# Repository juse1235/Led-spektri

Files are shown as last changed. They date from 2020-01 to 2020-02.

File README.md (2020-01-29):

# Led-spektri
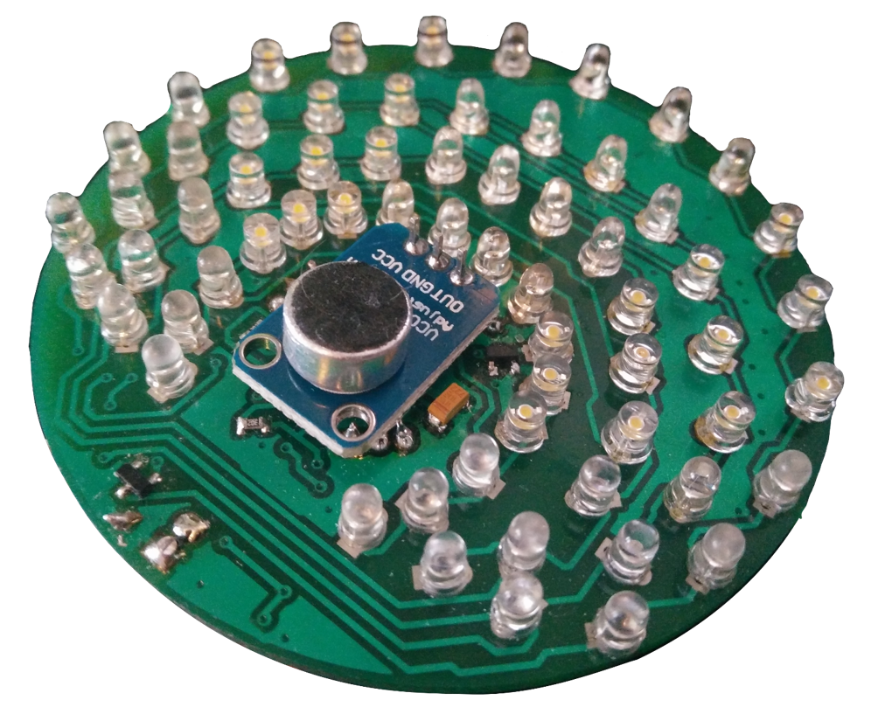
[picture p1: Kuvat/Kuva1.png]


Tuntuiko normaali haalarisalama liian yksinkertaiselta? Epäiletkö, että juotettavia LEDejä ei voi olla liikaa? Oletko aina haaveillut haalarimerkistä, jonka nähtyään kanssaopiskelijat pyörtyvät ihastuksesta?

Mikäli näin on, olet selvästikin motivoitunut nousemaan seuraavalle tasolle yöllisessä yökerhojen ja pystärien bling-bling-loisteessa. Tämä tanssilattioiden katseenvangitsija tarjoaa ainutkertaisen mahdollisuuden turruttaa itsensä vinoon juottuneille komponenteille ja v*tutukselle. Älä missaa tilaisuutta! Minä en missaisi.

Komponentit

| Tyyppi |	Määrä  |	Huom |
| --- | --- | --- |
| Atmega328PB-AU  |1 |	Myös 328P voi toimia, mutta vaatii muutoksia kääntäjään |
| LED, 3 mm, jalallinen	|64 |	Ei värikoodia – käytä mielikuvitusta |
| Transistori, SOT-23|16 |	Käytössä MMBT4401, ei suurempaa väliä mallista, hyvä kuitenkin kestää vähintään 20 mA virtaa |
| Vastus, 0603 – 0805, 1+ kOhm | 16 |		Transistorien ohjaus |
| Etuvastus, 0805	|8	| Kirkkauden säätö, 100 – 500 ohmia lienee hyvä, säätää myös virrankulutusta, tekijällä käytössä 300 ohmia |
| Isohko vastus, noin 5 kOhm, 0603 |2	 | |
| Regulaattori, LP2985 – 3.3 |	1	| |
| Kondensaattori, 100 nF, 0805|	1	| |
| Kondensaattori, 10 uF, 0805|	1	| |
| Sulake, 500 mA, 1206	|1	| |
| Oskillaattori, 16 MHz |	1 |	Käytössä CSTCE16M0V53-R0 |
| MAX4466-mikrofonimoduuli |	1 |	Mikrofoneja löytyy eri herkkyyksillä, voi olla tuurissaan, mikä on käyttökelpoinen. Electret sinisellä piirilevyllä on toiminut toistaiseksi.|

## Yleinen toimintaperiaate
Ledien toimintaperiaate on samankaltainen kuin haalarisalamassakin, eli ledejä vilkutetaan matriisissa sarakkeittain säätämällä, mikä sarake saa yhteyden maahan ja suljettua virtapiirin. 

Mikrofoni kuuntelee ääntä, ja mikrokontrolleri lukee siitä tulevaa analogista signaalia jatkuvalla syötöllä. Näytepätkän ollessa valmis mikrokontrolleri tekee siitä fft-muunnoksen, joka voidaan esittää ledeillä.

Tähän merkkiin ei otettu edes mahdollisuudeksi käyttää 9 voltin paristolla, vaan käyttöjännite otetaan aina 5 voltin jännitelähteestä (lue: USB-kaapelin kautta varavirtalähteestä).

## Tarkempi piirikaavion analyysi
Piirikaavion olisi voinut päivittää paljon helpommin luettavaksi ja oikeille arvoille, jos Kicad 5.0 ei olisi niin epäyhteensopiva Kicad 4 -versioiden kanssa. 

Käyttöjännite tulee mikrokontrollerille ja 3,3 voltin regulaattorille sulakkeen kautta. Sulakkeen tehtävänä on luonnollisesti edes hieman suojata komponentteja oikosuluilta sun muilta lapsuksilta. Tässä otettiin mallia Arduinosta. Regulaattorin tarkoituksena on vain ja ainoastaan tuottaa tasaista käyttöjännitettä mikrofonimoduulille ja asettaa analoginen referenssitaso mikrokontrollerille mikrofonimoduulin analogisen signaalin lukua varten. 10 mikrofaradin kondensaattori C1 tasoittaa käyttöjännitteen pahimmat häiriöt, ja kondensaattori C_small (oikea arvo 100 nF) tekee saman 3,3 voltin linjalle.

Toisin kuin haalarisalamassa, tässä projektissa tarvitaan transistoreita rajoittamaan mikrokontrollerin kuormaa. Riittävän kirkkauden takaamiseksi ledin virraksi on hyvä määritellä noin 15 mA. Transistoreiksi päätyivät MMBT3904-transistorit, jotka perustuvat NPN-teknologiaan. Lähtökohtaisesti MOSFET-transistorienkin pitäisi toimia ihan yhtä hyvin, kunhan paketointi on sama. Transistorit vaativat vastukset kantavirran rajoittamiseksi (1 kOhmin vastukset piirikaaviossa ja jäljempänä esitetyssä piirilevyssä). Todennäköisesti arvoltaan suuremmatkin vastukset toimisivat aivan yhtä hyvin. 

##### HUOM!Projektia kokeiltiin toteuttaa myös puolella transistorimäärällä, mutta mikrokontrolleri ei kyennyt antamaan riittävästi virtaa yhden sarakkeen ledeille yhtä aikaa. Tämän korjaaminen vaatii joko todella herkkiä ja kirkkaita ledejä ja/tai koodimuutoksia, jolloin ainoastaan yksi led olisi samaan yhtä aikaa päällä (nyt maksimissaan kahdeksan).

Oskillaattori on geneerinen 16 megahertsin malli sisäänrakennetulla kuormakapasitanssilla, jollaisia näkee muun muassa Arduino Nanossa. Myös 20 megahertsin kidettä voi käyttää, mutta se vaatii muutoksia koodiin ja Atmegan… ööö, fuse… sulake ei liene oikea termi. Joka tapauksessa ”fuse”:ille pitää löytää oikeat asetukset.

Yksinkertaisuuden vuoksi mikrofonin kanssa päädyttiin vahvistimen sisältävään valmiiseen moduuliin. Moduuli tuottaa analogista signaalia, joka välitetään Atmegan ADC-pinniin, ja josta Atmega ottaa näytepätkän.

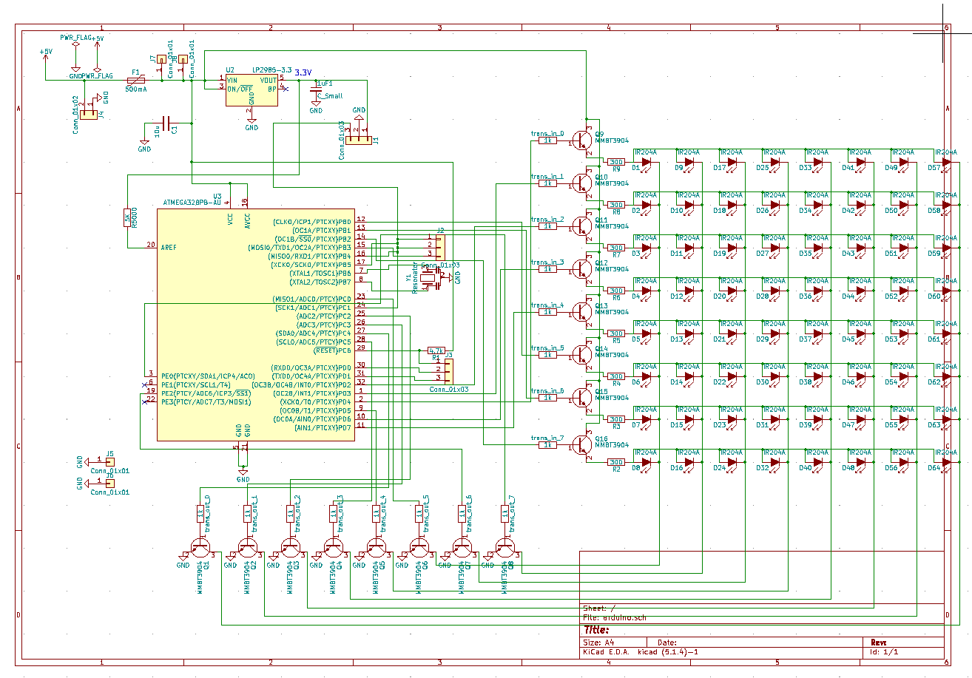
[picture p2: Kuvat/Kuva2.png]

Kuten tarkimmat jo saattavat huomata, tekijä ei osannut tekovaiheessa tehdä ihmisystävällisiä kytkentöjä.

## Piirilevy
Tilanpuute oli valtava ongelma varsinaisen piirilevyn suunnittelun kanssa. Tästä syystä kaikkia komponentteja ei voitu sijoittaa levyn takapuolelle helpon korjattavuuden takaamiseksi, vaan osa komponenteista ja mikrofonimoduuli oli juotettava etupuolelle.

Yleinen ohje juottamiseen: juota ensin yksi komponentin nurkka kiinni niin, että komponentin muutkin juotoskohdat ovat paikallaan ja komponentti on oikeassa asennossa. Tämän jälkeen voi helposti juottaa loput paikat.

Juottaminen on hyvä aloittaa mikrokontrollerista. Tekijä juotti piirin reippaalla juoksutteella ja reippaalla tinankäytöllä, jolloin myös kontrollerin jalat olivat juottuneet yhteen. Tämän jälkeen ylimääräinen tina oli helppoa imeä tinaimunauhalla.

Muiden pintaliitoskomponenttien juottamisessa ei ole varsinaisesti mitään mainittavaa. U2 alemmassa kuvassa on 3,3 voltin regulaattori.
Kun pintaliitoskomponentit on juotettu, J7 ja J6 on yhdistettävä hyppylangalla. Miksi näin? Tilanpuutteen takia maatasoa ei ole muuten yhdistetty kontrollerin yläpuolelle ollenkaan. Onneksi tämä on matalan taajuuden sovellutus, joten tämmöiset temput ovat sallittuja...

Etupuolella on mainittava ledien juottamisesta sen verran, että pitkä jalka (anodi) menee ympyrän muotoiseen juotospisteeseen, ja lyhyt jalka (katodi) menee neliön muotoiseen juotospisteeseen. Kokemuksen jykevällä rintaäänellä voi sanoa, että juottakaa ledit myös mieluummin etupuolelle kuin takapuolelle. Mikrofonimoduulin ja piirilevyn väliin on suositeltavaa laittaa jotakin eristettä oikosulun välttämiseksi. Tantaalikondensaattorin viivalla merkitty pääty menee aina positiiviseen jännitteeseen kaiken järjen vastaisesti (etupuolen 10 mikrofaradin konkka). 

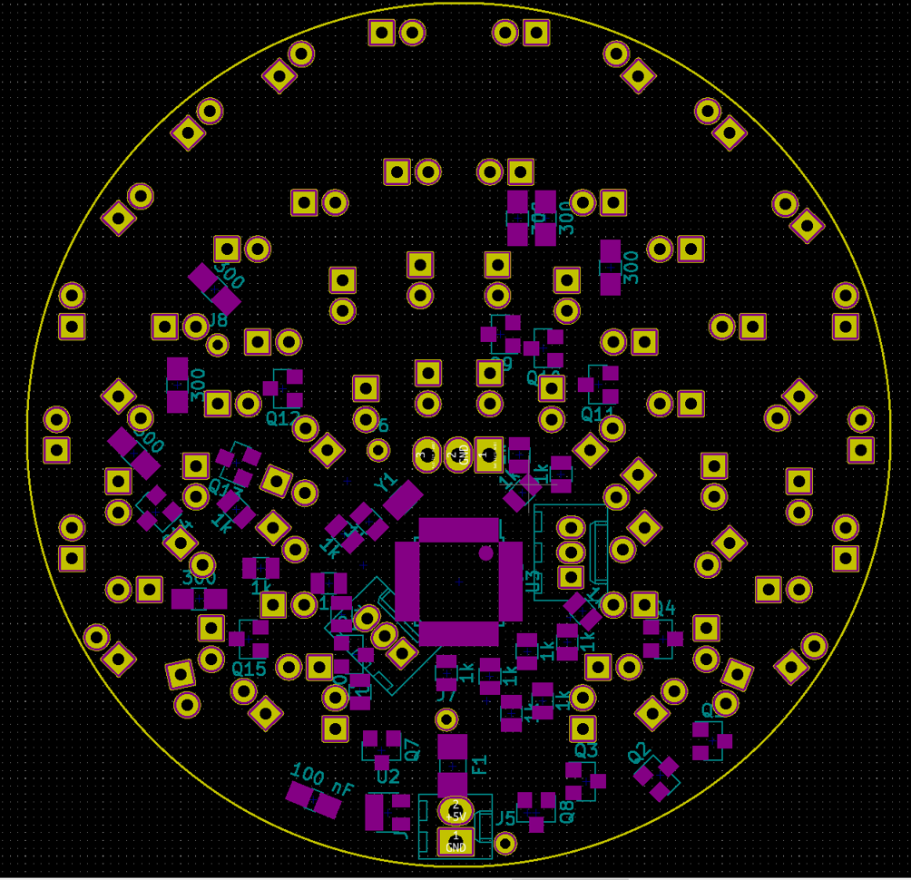
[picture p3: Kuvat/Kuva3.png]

Levyn takapuoli

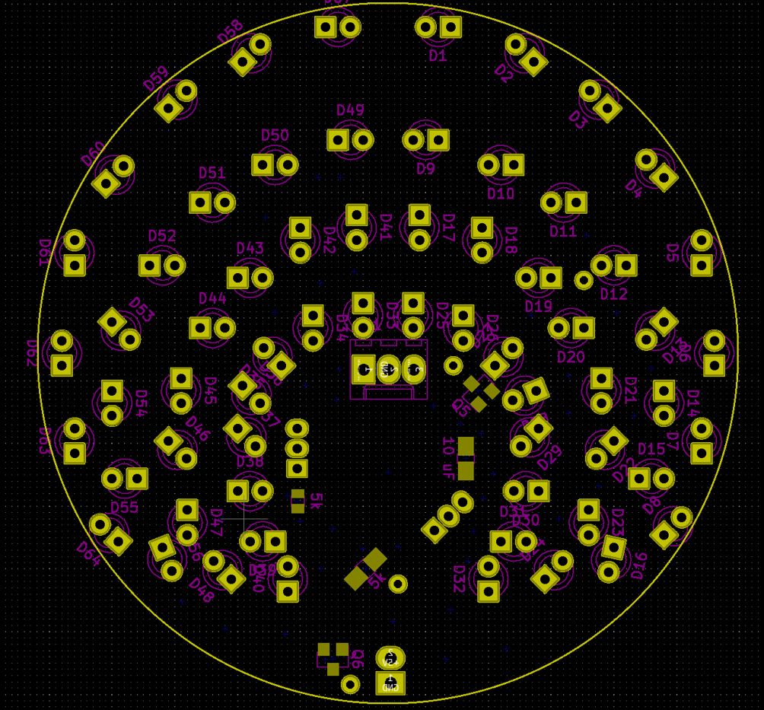
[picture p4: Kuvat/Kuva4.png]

Levyn etupuoli

## Ohjelmointi
Ohjelmointi tapahtuu ISP-väylän kautta. ArduinoISP on tässä suositeltava ohjelmoija. Piirilevylle jätettiin ohjelmointipaikat myös UART-ohjelmointia varten, mutta niitä ei tässä tapauksessa tarvita ollenkaan. Tulevaisuuden generaatioista ne voikin poistaa tilaa säästääkseen.

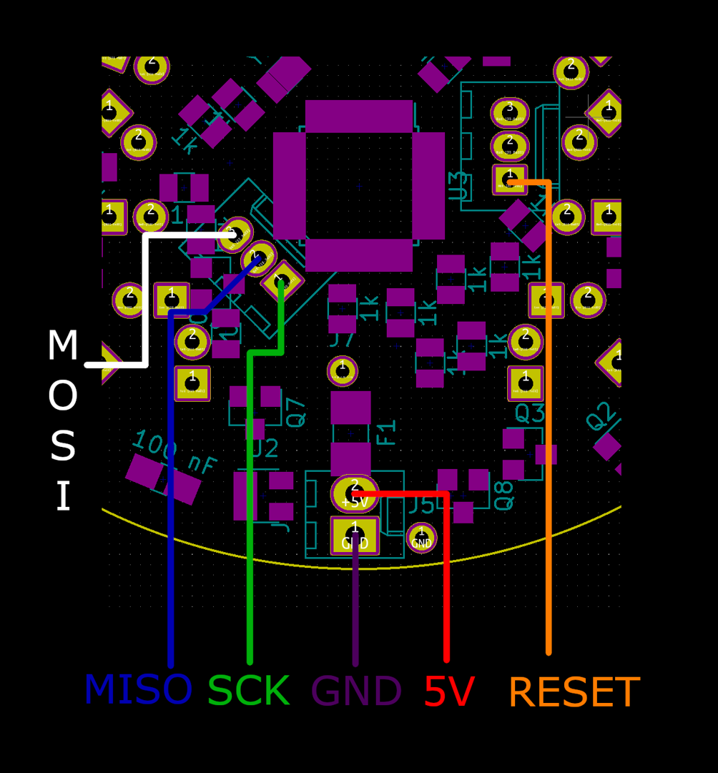
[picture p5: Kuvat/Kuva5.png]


##### Komennot Windowsille:

avrdude -C "C:\Program Files (x86)\Arduino\hardware\tools\avr\etc\avrdude.conf" -c avrisp -p m328pb -B3 -P COM7 -b 19200 -U flash:w:merkki.hex

avrdude -C "C:\Program Files (x86)\Arduino\hardware\tools\avr\etc\avrdude.conf" -c avrisp -p m328pb -B3 -P COM7 -b 19200 -U lfuse:w:0xff:m -U hfuse:w:0xde:m efuse:w:0x05:m

Jos avrdude.exe:ä ei ole asetettu Windowsin ympäristömuuttujiin, on edellä mainitut komennot ajettava ”Arduino\hardware\tools\avr\bin”-kansiosta. Polut ja oikea sarjaportti pitää toki tarkistaa tapauskohtaisesti.

##### Testaamattomat komennot Linuxille ja Macille:

avrdude -c avrisp -p m328pb -B3 -P /dev/ttyUSB0 -b 19200 -U flash:w:merkki.hex

avrdude -c avrisp -p m328pb -B3 -P /dev/ttyUSB0 -b 19200 -U lfuse:w:0xff:m -U hfuse:w:0xde:m efuse:w:0x05:m

Atmel Studio 7:llä tehty koodi ei ole mitään kauneinta katseltavaa, mutta joka tapauksessa se toimii. ChaN AVR FFT -kirjasto on otettu lievästi editoituna AVRFreaks-foorumilta ( https://www.avrfreaks.net/forum/64-point-fft-elm-chan-library), ja kirjasto löytyy myös erilaisina variaatioina eri puolilta internetiä. Alun perin koodi on oletettavasti julkaistu Elm-chanin kotisivulla (http://elm-chan.org/works/akilcd/report_e.html)

## Fyysinen rakenne
Kuumaliimaa kannattaa hyödyntää ainakin varsinaisen mikrofonielementin ja mikrofonimoduulipiirilevyn liitoskohdassa, sillä isku taittaa mikrofonin helposti. Lisäksi käyttöjännitetuloon on hyvä tehdä liimalla vedonpoisto.
Haalarimerkkiin integroimiseen ei ole suoria ohjeita, mutta on suositeltavaa tehdä painettuun merkkiin valmiit reiät. Mielikuvituksen ja insinööritaitojen käyttö on aiheellista, sillä ledien asentaminen merkin läpi haalarisalaman mukaisesti ei ole huollettavuuden takia järkevää.

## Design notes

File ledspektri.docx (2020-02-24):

Spektrianalysaattori – LED-mössö haalareihin

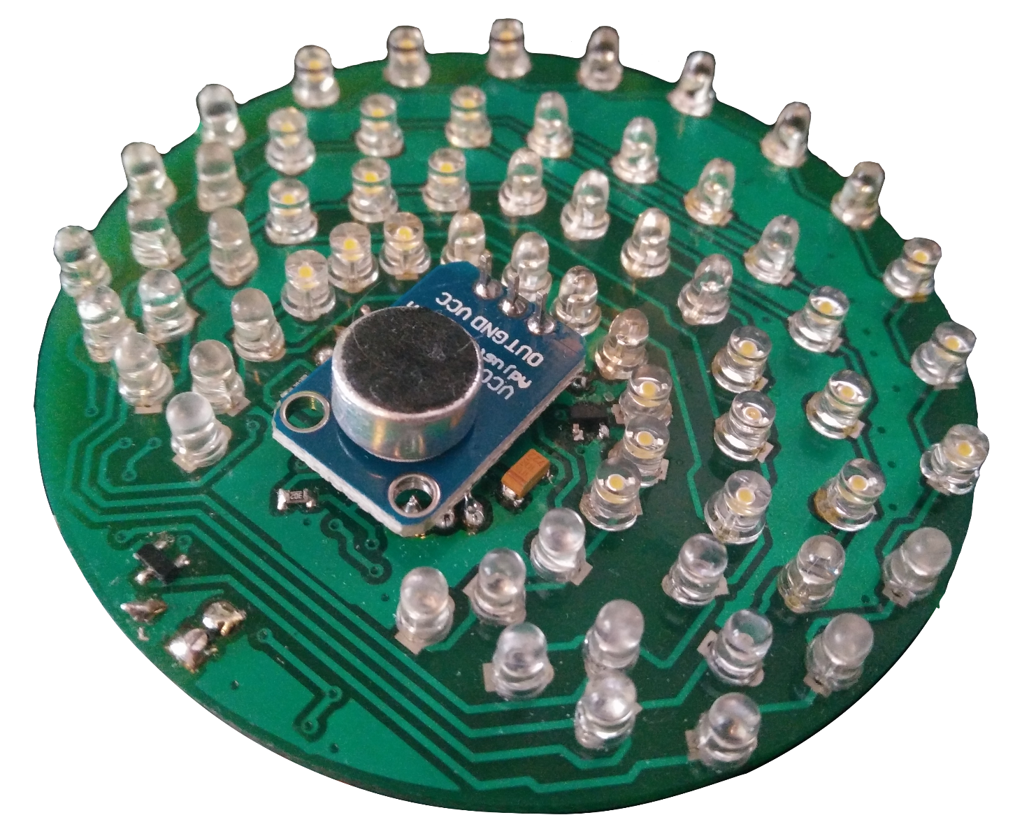
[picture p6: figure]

Tuntuiko normaali haalarisalama liian yksinkertaiselta? Epäiletkö, että juotettavia LEDejä ei voi olla liikaa? Oletko aina haaveillut haalarimerkistä, jonka nähtyään kanssaopiskelijat pyörtyvät ihastuksesta?

Mikäli näin on, olet selvästikin motivoitunut nousemaan seuraavalle tasolle yöllisessä yökerhojen ja pystärien bling-bling-loisteessa. Tämä tanssilattioiden katseenvangitsija tarjoaa ainutkertaisen mahdollisuuden turruttaa itsensä vinoon juottuneille komponenteille ja v*tutukselle. Älä missaa tilaisuutta! Minä en missaisi.

Historiikki

Jo fuksivuonna pienen teekkarinalun mielessä muhi ajatus pidemmälle viedystä haalarimerkistä, joka tekisi jotakin erilaista. Jotakin, joka aiheuttaisi edes pientä kysymysmerkkiä kanssaeläjissä Oulun yössä. Syntyi idea omasta haalareihin kiinnitettävästä spektrianalysaattorista, johon löytyi Arduino-pohjalle tehtyjä valmiita ohjeita netistä pilvin pimein. Kummasti yhtäkään ei ollut suunniteltu haalareihin sopivaksi.

Sopivan markkinaraon löydyttyä oli aika pyörähtää Fablabilla jyrryyttämässä Arduinoon shieldinä sopiva piirilevy. Latomisen jälkeen pikainen softaus ja kappas – nythän käsissä oli toimiva kapistus. Vielä polkupyörän sisäkumista tehty IP67-suojaus, niin sehän oli täydellinen!

Ylpeää fuksiahan eivät haitanneet kyhäelmän paino, joka oli luokkaa Jupiter, tai ulkonäkö, jonka rinnalla renkaan alle jäänyt oravakin näytti hyvän mielen taideteokselta. Toisen lahkeen valuminen painon alla kohti nilkkaa toki pientä kysymysmerkkiä kaupungilla aiheuttikin, mutta kohteliaana kansana suurin osa oululaisista osasi pitää turpansa kiinni.

Wappuna muuan kanssaopiskelija uskalsi viimein avata suunsa ja heitti ilmoille kysymyksen koskien tehokkaampaa ja hiotumpaa merkin rakennetta. Huolimatta tiukasta puolustuspuheesta, miksi tämä rakenne on ehdoton ja paras, kysymys jäi kummittelemaan mieltä.

Loppuvuoden 2017 ja alkuvuoden 2018 aikana syntyi monta konseptia aiheesta. Turhankin monta, sillä suurin ongelma oli joka kerta väärän kokoinen tulojännitteen stabilointikondensaattori. On myös mainitsemisen arvoista, kuinka monta komponenttia pystyy juottamaan väärinpäin alkaen ledeistä ja jatkuen mikrokontrollerin kautta tantaalikondensaattoriin. Jokaisesta tuli mitä mielenkiintoisimpia ominaisefektejä tai -hajuja.

Lopulta pitkällisen yrittämisen jälkeen tähdet osuivat kohdalleen, ja uusi kompakti led-merkki oli syntynyt. Suunnitellusti piirilevy oli neulan halkaisijan verran pienempi kuin normaalikokoinen haalarimerkki, mikä laskettakoon voitoksi.

Merkki luvattiin elektroniikkakerhon käyttöön jo vaalikokouksessa vuoden 2018 lopulla, mutta asioiden tapahtumisen ja tapahtumattomuuden takia näin ei käynyt vielä 2010-luvulla. Nyt uuden vuosikymmenen pamahdettua käyntiin olikin korkea aika tarjota elektroniikkakerholle lisää kivaa räpellettävää nykyisille ja tuleville kerhossa kävijöille.

Make elekerho great again!

Juuso Tapaninen 2020

Komponentit

Tyyppi | Määrä | Huom
Atmega328PB-AU | 1 | Myös 328P voi toimia, mutta vaatii muutoksia kääntäjään
LED, 3 mm, jalallinen | 64 | Ei värikoodia – käytä mielikuvitusta
Transistori, SOT-23 | 16 | Käytössä MMBT3904, ei erityisen tarkkaa mallista
Vastus, 0603 – 0805, 1+ kOhm | 16 | Transistorien ohjaus
Etuvastus, 0805 | 8 | Kirkkauden säätö, 100 – 500 ohmia lienee hyvä, säätää myös virrankulutusta, tekijällä käytössä 300 ohmia
Isohko vastus, noin 5 kOhm, 0603 | 2
Regulaattori, LP2985 – 3.3 | 1
Kondensaattori, 100 nF, 0805 | 1
Kondensaattori, 10 uF, 0805 | 1
Sulake, 500 mA, 1206 | 1
Oskillaattori, 16 MHz | 1 | Käytössä CSTCE16M0V53-R0
MAX4466-mikrofonimoduuli | 1 | Mikrofoneja löytyy eri herkkyyksillä, voi olla tuurissaan, mikä on käyttökelpoinen. Electret sinisellä piirilevyllä on toiminut toistaiseksi.

Yleinen toimintaperiaate

Ledien toimintaperiaate on samankaltainen kuin haalarisalamassakin, eli ledejä vilkutetaan matriisissa sarakkeittain säätämällä, mikä sarake saa yhteyden maahan ja suljettua virtapiirin.

Mikrofoni kuuntelee ääntä, ja mikrokontrolleri lukee siitä tulevaa analogista signaalia jatkuvalla syötöllä. Näytepätkän ollessa valmis mikrokontrolleri tekee siitä fft-muunnoksen, joka voidaan esittää ledeillä.

Tähän merkkiin ei otettu edes mahdollisuudeksi käyttää 9 voltin paristolla, vaan käyttöjännite otetaan aina 5 voltin jännitelähteestä (lue: USB-kaapelin kautta varavirtalähteestä).

Tarkempi piirikaavion analyysi

Piirikaavion olisi voinut päivittää paljon helpommin luettavaksi ja oikeille arvoille, jos Kicad 5.0 ei olisi niin epäyhteensopiva Kicad 4 -versioiden kanssa.

Käyttöjännite tulee mikrokontrollerille ja 3,3 voltin regulaattorille sulakkeen kautta. Sulakkeen tehtävänä on luonnollisesti edes hieman suojata komponentteja oikosuluilta sun muilta lapsuksilta. Tässä otettiin mallia Arduinosta. Regulaattorin tarkoituksena on vain ja ainoastaan tuottaa tasaista käyttöjännitettä mikrofonimoduulille ja asettaa analoginen referenssitaso mikrokontrollerille mikrofonimoduulin analogisen signaalin lukua varten. 10 mikrofaradin kondensaattori C1 tasoittaa käyttöjännitteen pahimmat häiriöt, ja kondensaattori C_small (oikea arvo 100 nF) tekee saman 3,3 voltin linjalle.

Toisin kuin haalarisalamassa, tässä projektissa tarvitaan transistoreita rajoittamaan mikrokontrollerin kuormaa. Riittävän kirkkauden takaamiseksi ledin virraksi on hyvä määritellä noin 15 mA. Transistoreiksi päätyivät MMBT3904-transistorit, jotka perustuvat NPN-teknologiaan. Lähtökohtaisesti MOSFET-transistorienkin pitäisi toimia ihan yhtä hyvin, kunhan paketointi on sama. Transistorit vaativat vastukset kantavirran rajoittamiseksi (1 kOhmin vastukset piirikaaviossa ja jäljempänä esitetyssä piirilevyssä). Todennäköisesti arvoltaan suuremmatkin vastukset toimisivat aivan yhtä hyvin.

HUOM! Projektia kokeiltiin toteuttaa myös puolella transistorimäärällä, mutta mikrokontrolleri ei kyennyt antamaan riittävästi virtaa yhden sarakkeen ledeille yhtä aikaa. Tämän korjaaminen vaatii joko todella herkkiä ja kirkkaita ledejä ja/tai koodimuutoksia, jolloin ainoastaan yksi led olisi samaan yhtä aikaa päällä (nyt maksimissaan kahdeksan).

Oskillaattori on geneerinen 16 megahertsin malli sisäänrakennetulla kuormakapasitanssilla, jollaisia näkee muun muassa Arduino Nanossa. Myös 20 megahertsin kidettä voi käyttää, mutta se vaatii muutoksia koodiin ja Atmegan… ööö, fuse… sulake ei liene oikea termi. Joka tapauksessa ”fuse”:ille pitää löytää oikeat asetukset.

Yksinkertaisuuden vuoksi mikrofonin kanssa päädyttiin vahvistimen sisältävään valmiiseen moduuliin. Moduuli tuottaa analogista signaalia, joka välitetään Atmegan ADC-pinniin, ja josta Atmega ottaa näytepätkän.

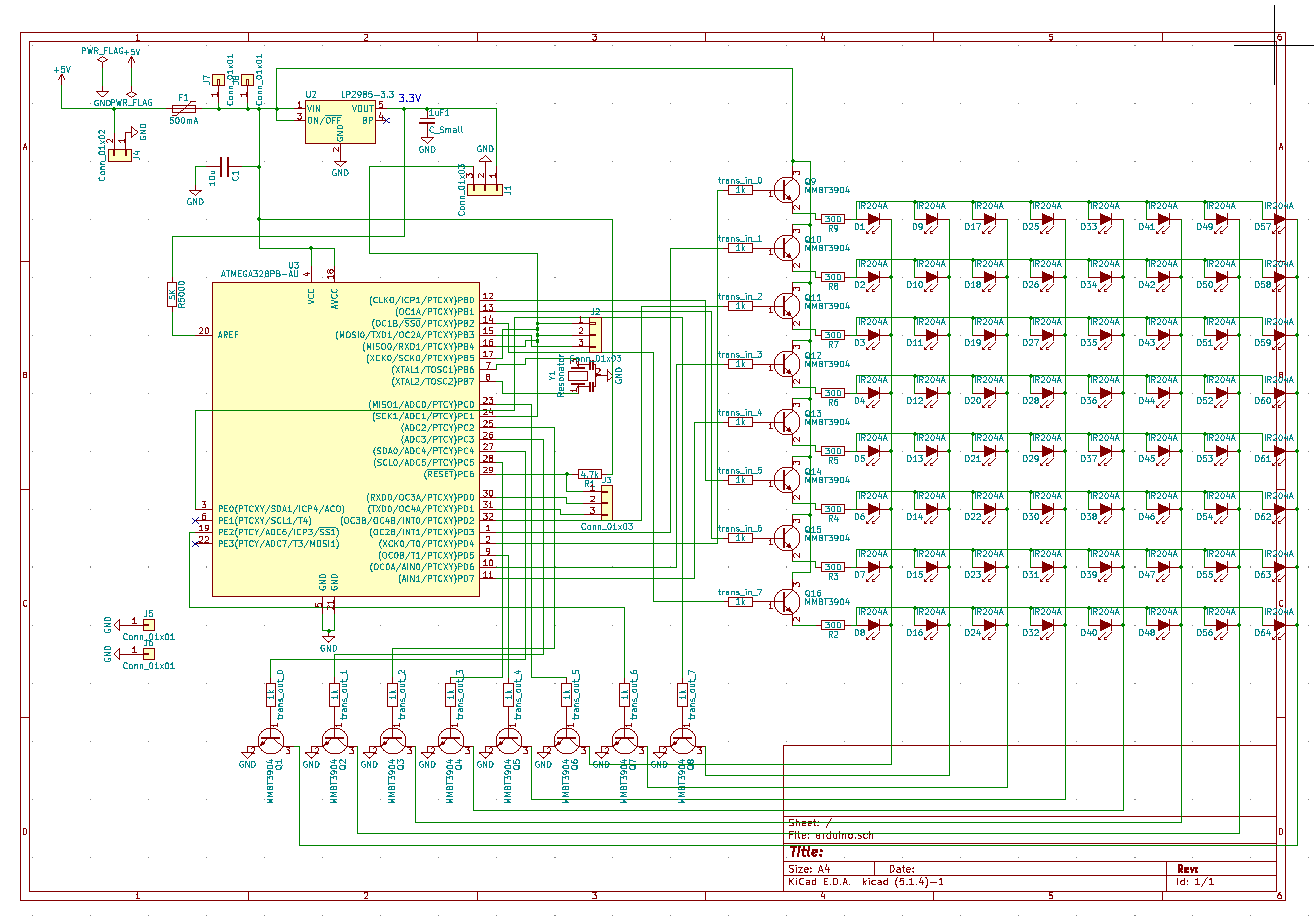
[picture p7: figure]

Kuten tarkimmat jo saattavat huomata, tekijä ei osannut tekovaiheessa tehdä ihmisystävällisiä kytkentöjä.

Piirilevy

Tilanpuute oli valtava ongelma varsinaisen piirilevyn suunnittelun kanssa. Tästä syystä kaikkia komponentteja ei voitu sijoittaa levyn takapuolelle helpon korjattavuuden takaamiseksi, vaan osa komponenteista ja mikrofonimoduuli oli juotettava etupuolelle.

Yleinen ohje juottamiseen: juota ensin yksi komponentin nurkka kiinni niin, että komponentin muutkin juotoskohdat ovat paikallaan ja komponentti on oikeassa asennossa. Tämän jälkeen voi helposti juottaa loput paikat.

Juottaminen on hyvä aloittaa mikrokontrollerista. Tekijä juotti piirin reippaalla juoksutteella ja reippaalla tinankäytöllä, jolloin myös kontrollerin jalat olivat juottuneet yhteen. Tämän jälkeen ylimääräinen tina oli helppoa imeä tinaimunauhalla.

Muiden pintaliitoskomponenttien juottamisessa ei ole varsinaisesti mitään mainittavaa. U2 alemmassa kuvassa on 3,3 voltin regulaattori.

Kun pintaliitoskomponentit on juotettu, J7 ja J6 on yhdistettävä hyppylangalla. Miksi näin? Tilanpuutteen takia maatasoa ei ole muuten yhdistetty kontrollerin yläpuolelle ollenkaan. Onneksi tämä on matalan taajuuden sovellutus, joten tämmöiset temput ovat sallittuja...

Etupuolella on mainittava ledien juottamisesta sen verran, että pitkä jalka (anodi) menee ympyrän muotoiseen juotospisteeseen, ja lyhyt jalka (katodi) menee neliön muotoiseen juotospisteeseen. Kokemuksen jykevällä rintaäänellä voi sanoa, että juottakaa ledit myös mieluummin etupuolelle kuin takapuolelle. Mikrofonimoduulin ja piirilevyn väliin on suositeltavaa laittaa jotakin eristettä oikosulun välttämiseksi. Tantaalikondensaattorin viivalla merkitty pääty menee aina positiiviseen jännitteeseen kaiken järjen vastaisesti (etupuolen 10 mikrofaradin konkka).

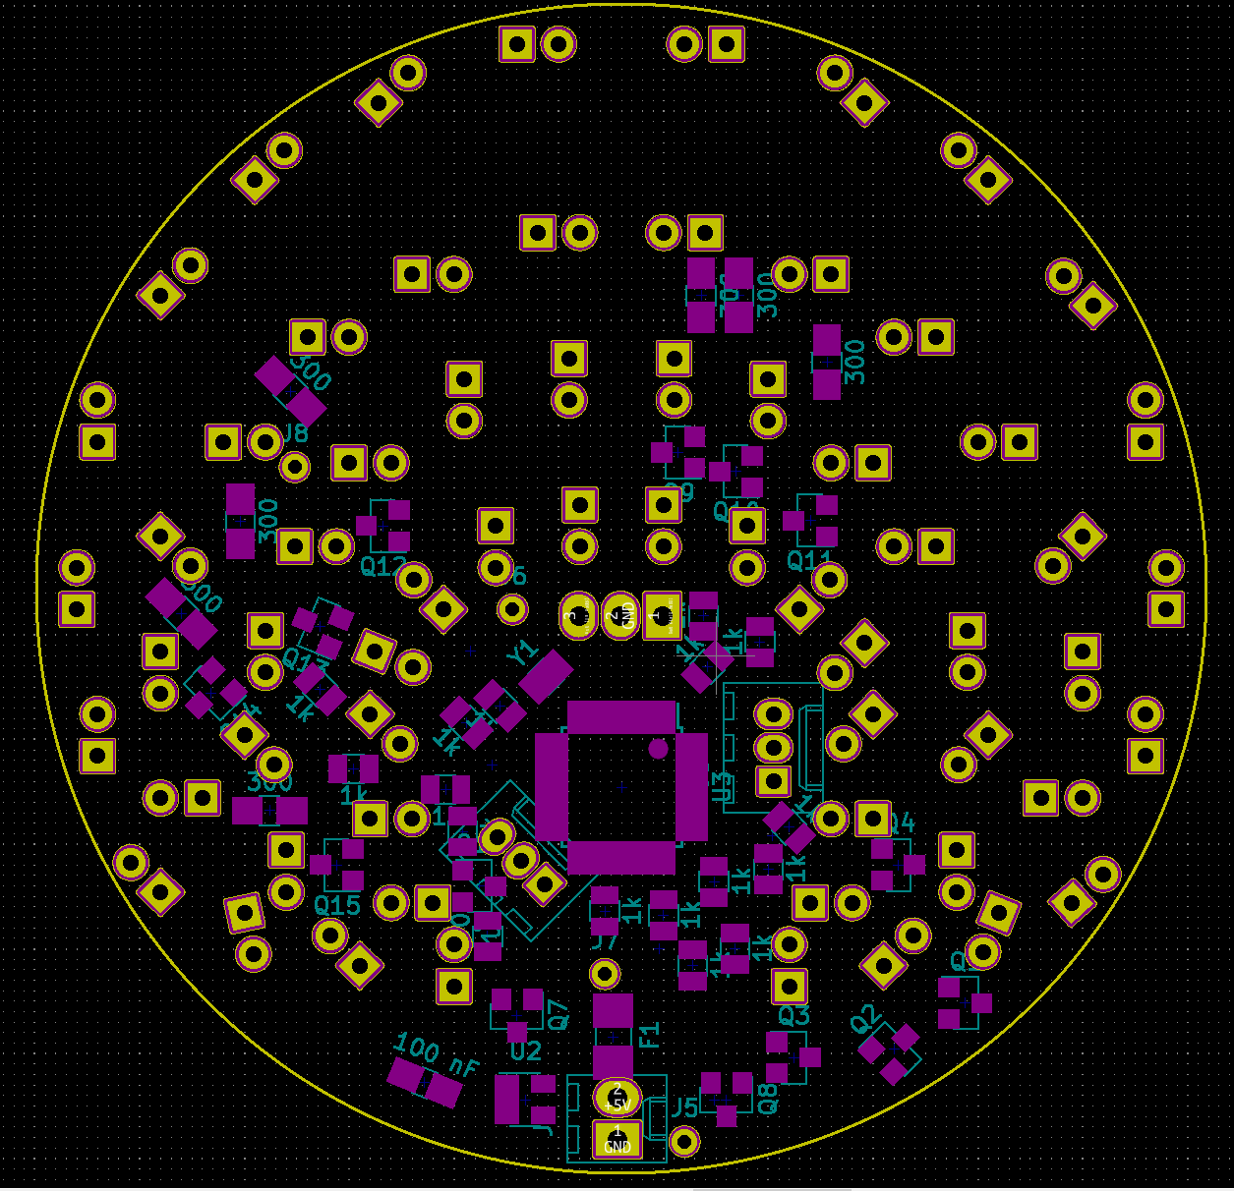
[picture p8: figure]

Levyn takapuoli

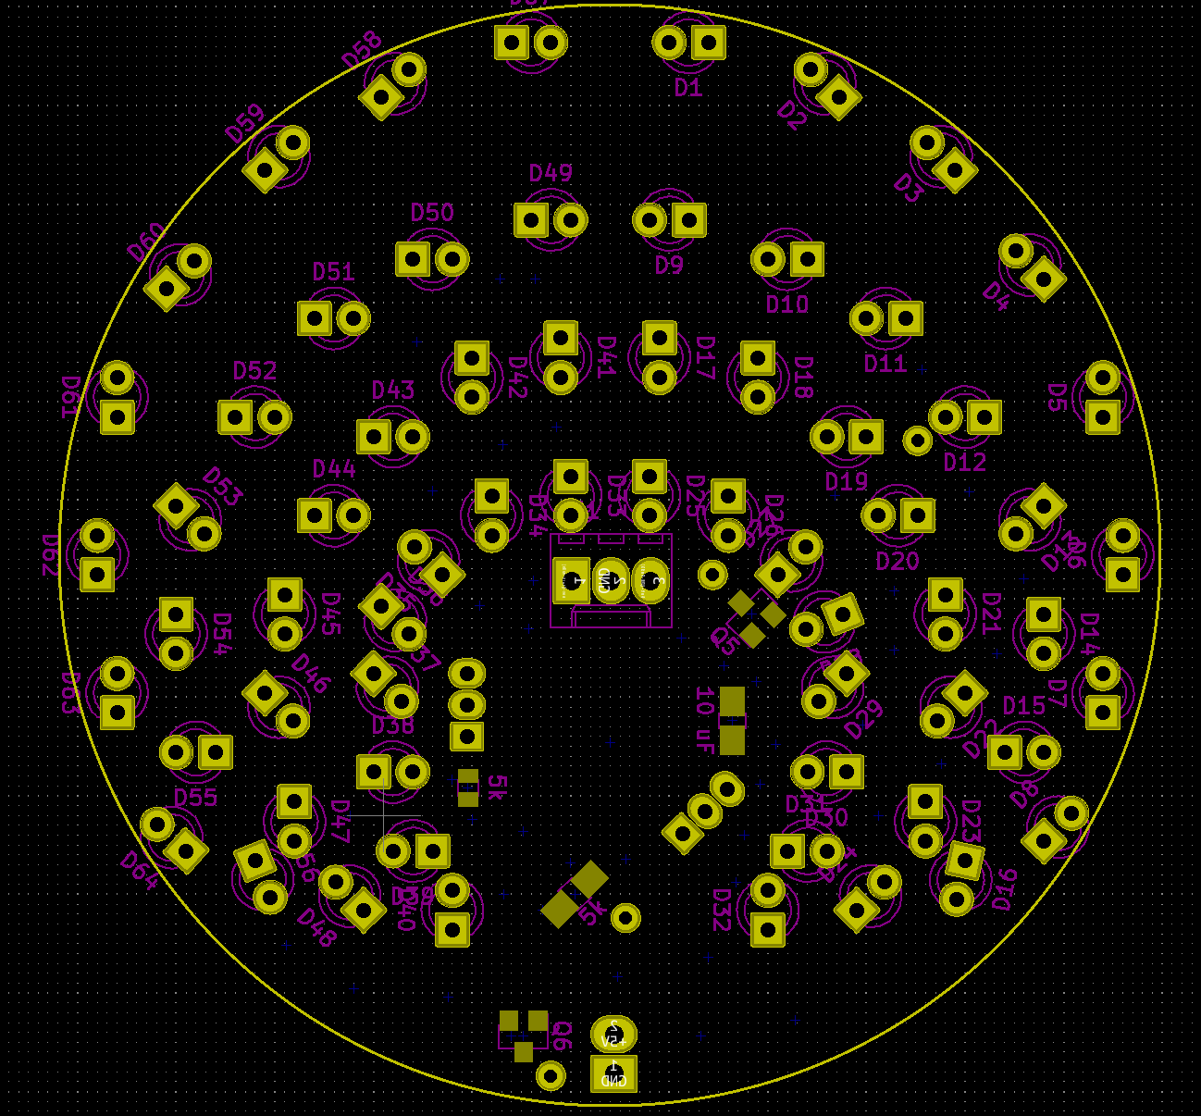
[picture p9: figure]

Levyn etupuoli

Ohjelmointi

Ohjelmointi tapahtuu ISP-väylän kautta. ArduinoISP on tässä suositeltava ohjelmoija. Piirilevylle jätettiin ohjelmointipaikat myös UART-ohjelmointia varten, mutta niitä ei tässä tapauksessa tarvita ollenkaan. Tulevaisuuden generaatioista ne voikin poistaa tilaa säästääkseen.

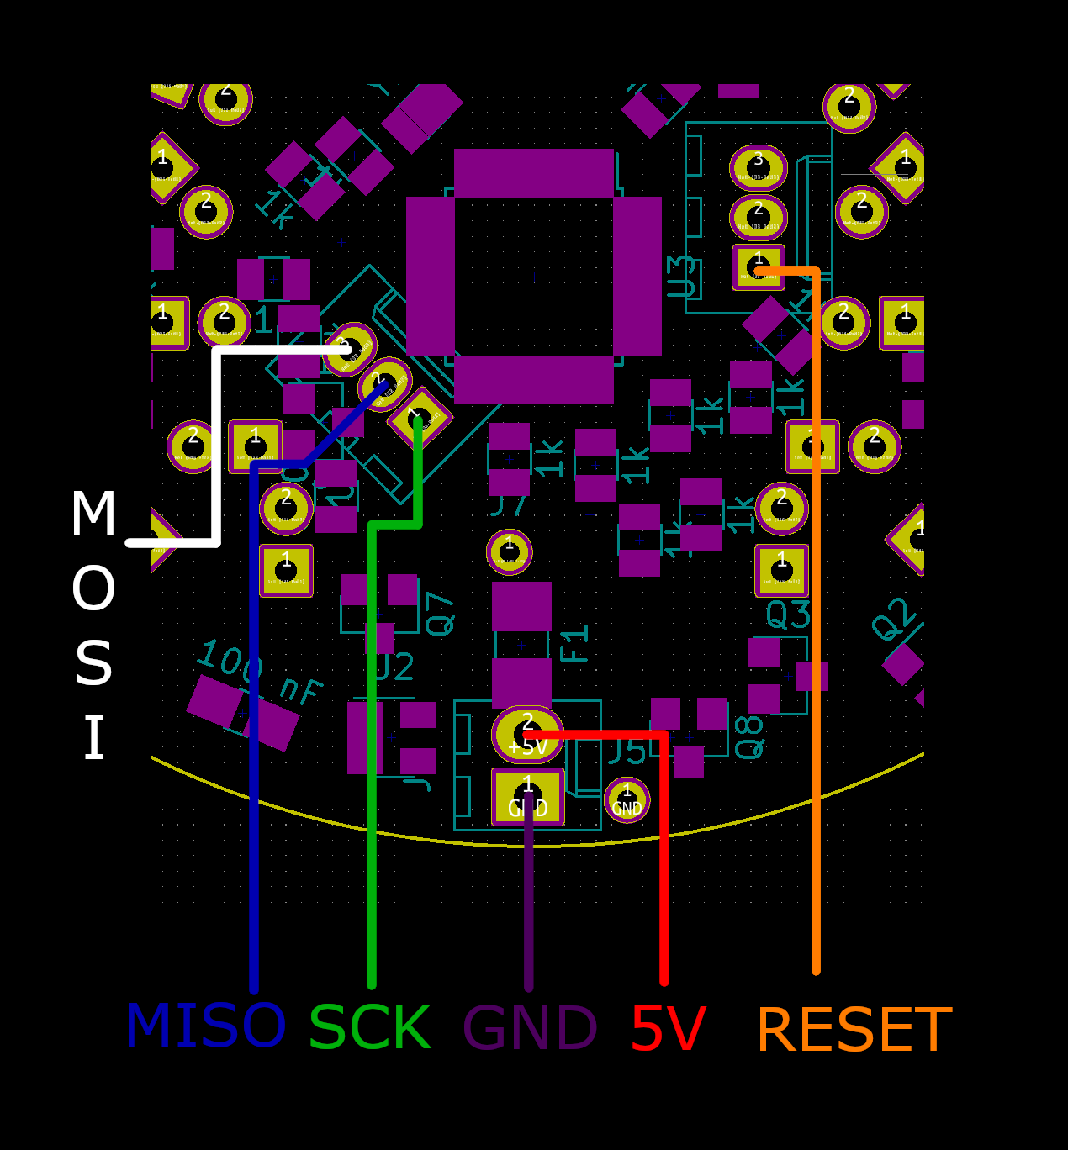
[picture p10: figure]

Ohjelmointikytkentä

Komennot Windowsille:

Ohjelmointi

Varsinainen ohjelma | avrdude -C "C:\Program Files (x86)\Arduino\hardware\tools\avr\etc\avrdude.conf" -c avrisp -p m328pb -B3 -P COM7 -b 19200 -U flash:w:merkki.hex
Fuset | avrdude -C "C:\Program Files (x86)\Arduino\hardware\tools\avr\etc\avrdude.conf" -c avrisp -p m328pb -B3 -P COM7 -b 19200 -U lfuse:w:0xff:m -U hfuse:w:0xde:m efuse:w:0x05:m

Jos avrdude.exe:ä ei ole asetettu Windowsin ympäristömuuttujiin, on edellä mainitut komennot ajettava ”Arduino\hardware\tools\avr\bin”-kansiosta. Polut ja oikea sarjaportti pitää toki tarkistaa tapauskohtaisesti.

Testaamattomat komennot Linuxille ja Macille:

Ohjelmointi

Varsinainen ohjelma | avrdude -c avrisp -p m328pb -B3 -P /dev/ttyUSB0 -b 19200 -U flash:w:merkki.hex
Fuset | avrdude -c avrisp -p m328pb -B3 -P /dev/ttyUSB0 -b 19200 -U lfuse:w:0xff:m -U hfuse:w:0xde:m efuse:w:0x05:m

Atmel Studio 7:llä tehty koodi ei ole mitään kauneinta katseltavaa, mutta joka tapauksessa se toimii. ChaN AVR FFT -kirjasto on otettu lievästi editoituna AVRFreaks-foorumilta ( https://www.avrfreaks.net/forum/64-point-fft-elm-chan-library), ja kirjasto löytyy myös erilaisina variaatioina eri puolilta internetiä. Alun perin koodi on oletettavasti julkaistu Elm-chanin kotisivulla (http://elm-chan.org/works/akilcd/report_e.html)

Fyysinen rakenne

Kuumaliimaa kannattaa hyödyntää ainakin varsinaisen mikrofonielementin ja mikrofonimoduulipiirilevyn liitoskohdassa, sillä isku taittaa mikrofonin helposti. Lisäksi käyttöjännitetuloon on hyvä tehdä liimalla vedonpoisto.

Haalarimerkkiin integroimiseen ei ole suoria ohjeita, mutta on suositeltavaa tehdä painettuun merkkiin valmiit reiät. Mielikuvituksen ja insinööritaitojen käyttö on aiheellista, sillä ledien asentaminen merkin läpi haalarisalaman mukaisesti ei ole huollettavuuden takia järkevää.

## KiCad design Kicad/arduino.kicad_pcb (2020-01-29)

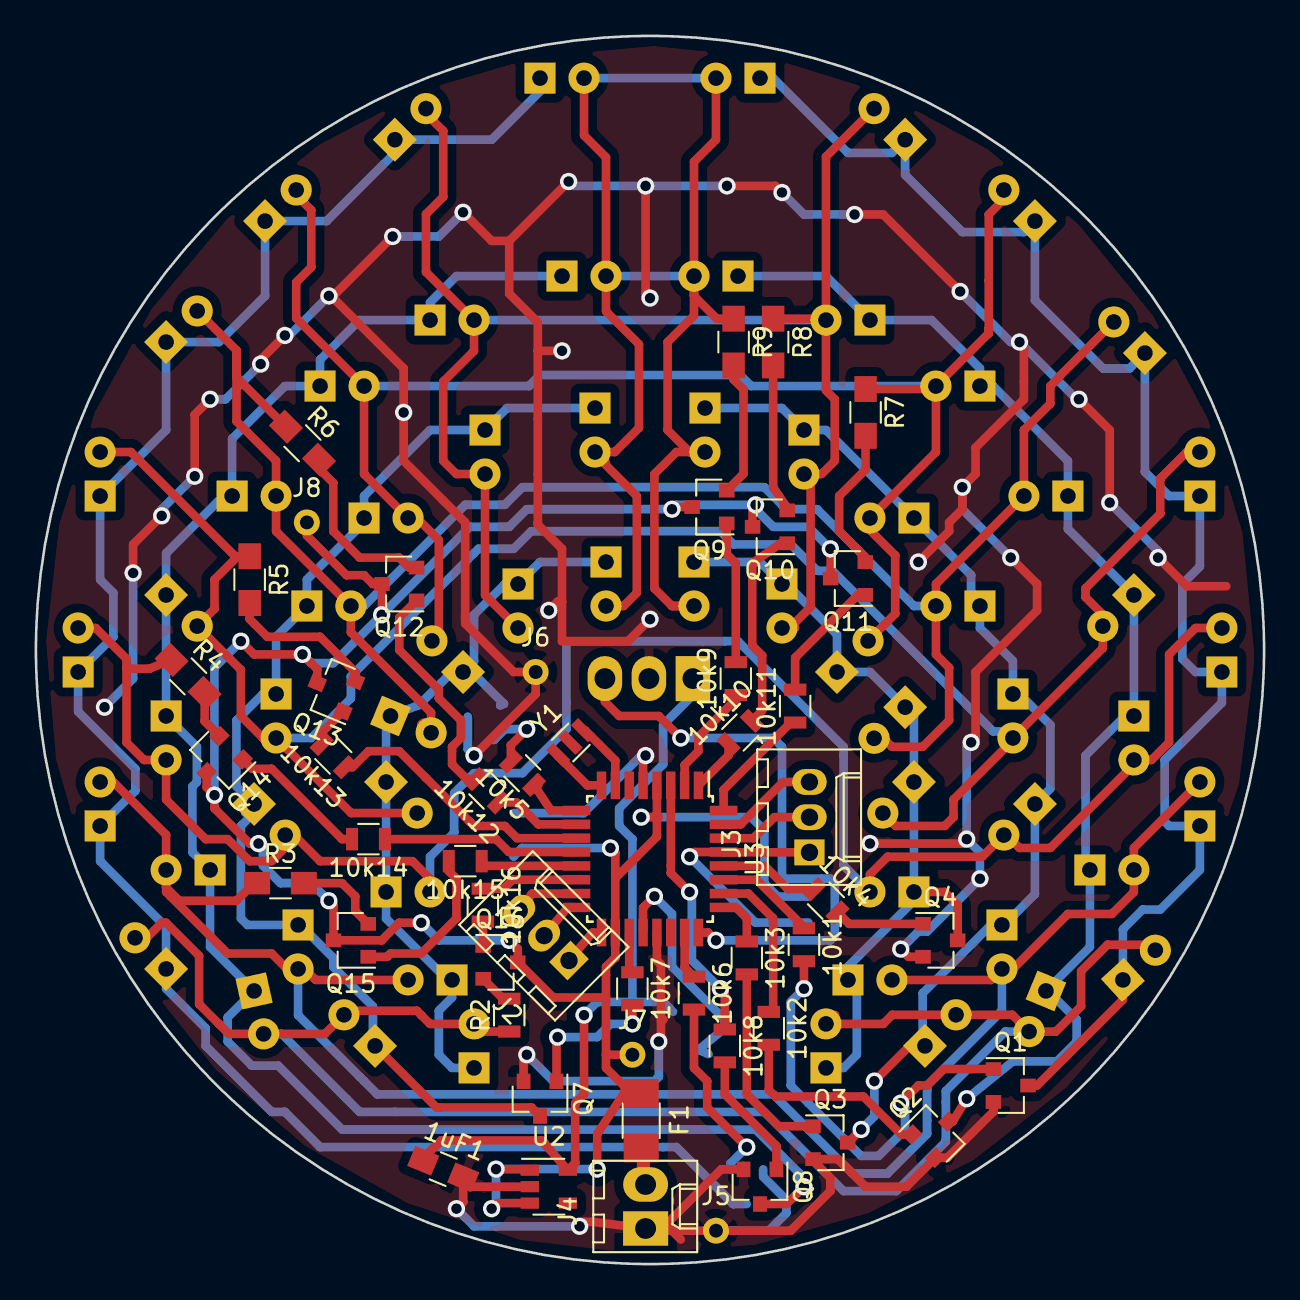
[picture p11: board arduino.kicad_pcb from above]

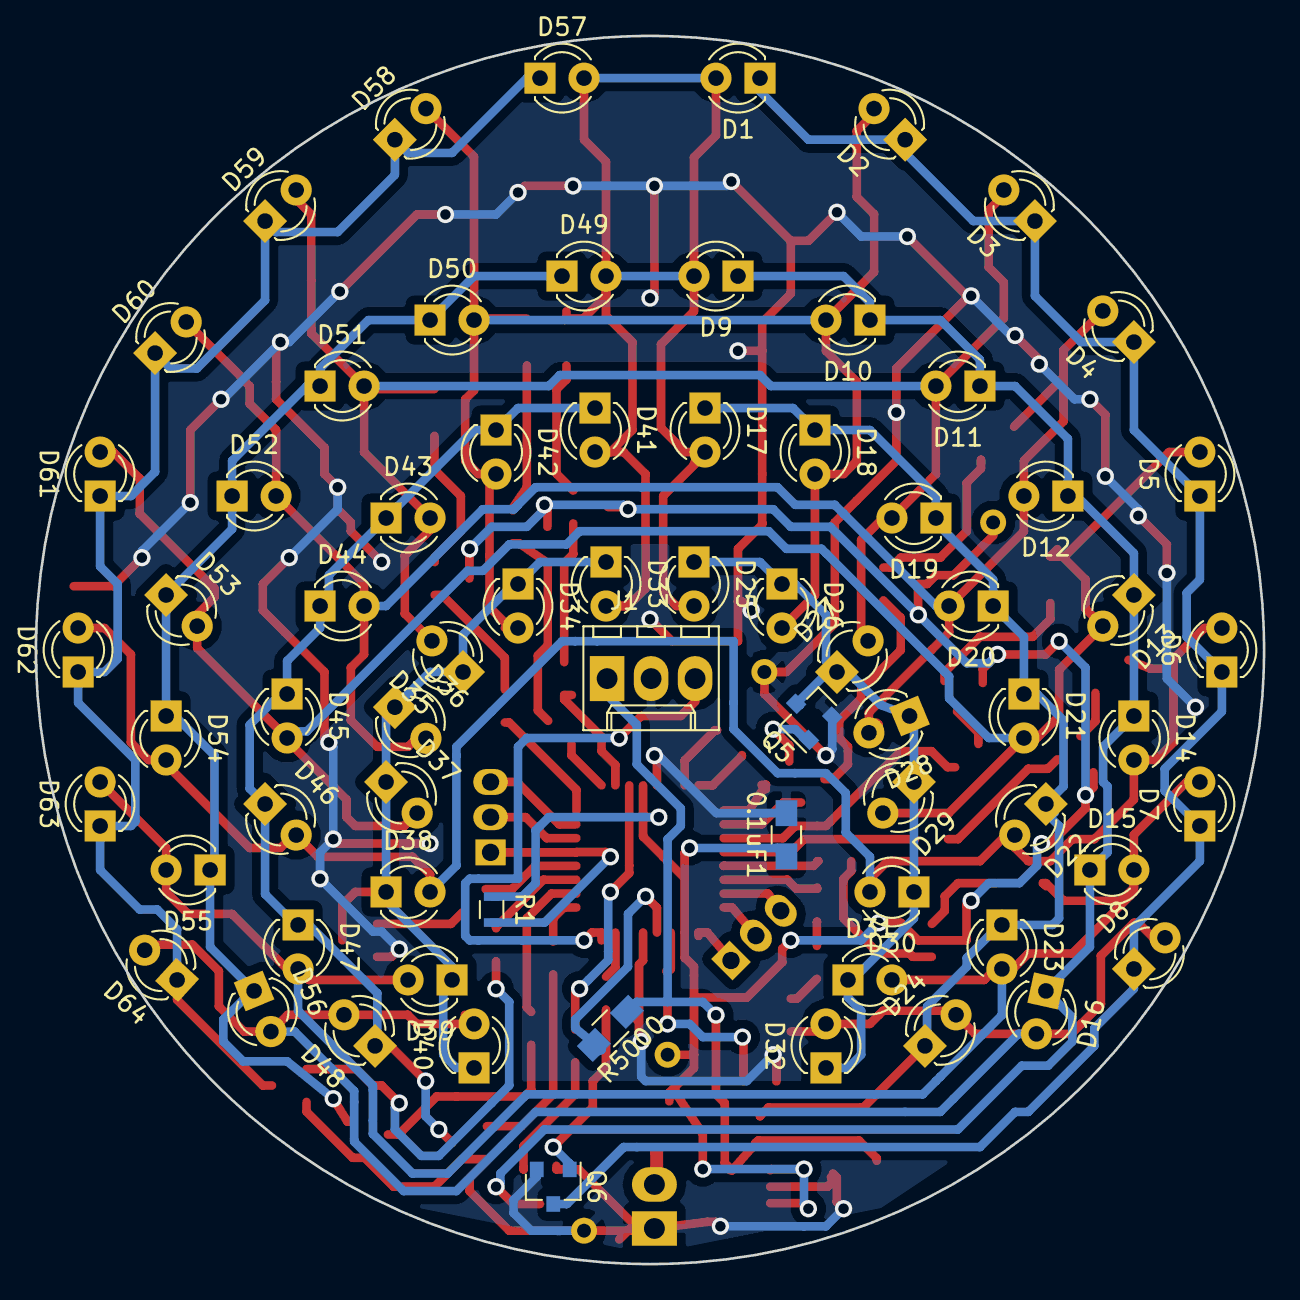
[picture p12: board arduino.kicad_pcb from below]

Board: 2 copper layers, 70.9 x 70.9 mm, 120 parts (70 on the bottom side), 70 nets.

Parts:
0.1uF1: C; C_0805_HandSoldering
1uF1: C_Small; C_0805_HandSoldering
10k1, 10k2, 10k3, 10k4, 10k5, 10k6, 10k7, 10k8, 10k9, 10k10, 10k11, 10k12, 10k13, 10k14, 10k15, 10k16: R; R_0805
D1, D2, D3, D4, D5, D6, D7, D8, D9, D10, D11, D12, D13, D14, D15, D16, D17, D18, D19, D20, D21, D22, D23, D24, D25, D26, D27, D28, D29, D30, D31, D32, D33, D34, D35, D36, D37, D38, D39, D40, D41, D42, D43, D44, D45, D46, D47, D48, D49, D50, D51, D52, D53, D54, D55, D56, D57, D58, D59, D60, D61, D62, D63, D64: IR204A; LED_D3.0mm
F1: 500mA; Fuse_SMD1206_Wave
J1: Conn_01x03; Molex_KK-6410-03_03x2.54mm_Straight
J2, J3: Conn_01x03; kolmijalka
J4: Conn_01x02; Molex_KK-6410-02_02x2.54mm_Straight
J5, J6, J7, J8: Conn_01x01; Measurement_Point_Round-TH_Small
Q1, Q2, Q3, Q4, Q5, Q6, Q7, Q8, Q9, Q10, Q11, Q12, Q13, Q14, Q15, Q16: MMBT3904; SOT-23
R1: 10kohm; L_0603
R2: R; R_0805
R3, R4, R5, R6, R7, R8, R9: R; R_0805_HandSoldering
R5000: 5K; R_0805_HandSoldering
U2: LP2985-3.3; SOT-23-5
U3: ATMEGA328PB-AU; TQFP-32_7x7mm_Pitch0.8mm
Y1: Resonator; resonator

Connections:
+5V: F1.2, J4.2
GND: 0.1uF1.2, 1uF1.2, J1.2, J4.1, J5.1, J6.1, Q1.2, Q2.2, Q3.2, Q4.2, Q5.2, Q6.2, Q7.2, Q8.2, U2.2, U3.5, U3.21, Y1.2
unnamed: 0.1uF1.1, F1.1, J7.1, J8.1, Q9.3, Q10.3, Q11.3, Q12.3, Q13.3, Q14.3, Q15.3, Q16.3, R1.1, U2.1, U2.3, U3.4, U3.18
unnamed: 1uF1.1, J1.1, R5000.1, U2.5
unnamed: 10k1.1, U3.27
unnamed: 10k1.2, Q1.1
unnamed: 10k2.1, U3.26
unnamed: 10k2.2, Q2.1
unnamed: 10k3.1, U3.25
unnamed: 10k3.2, Q3.1
unnamed: 10k4.1, U3.28
unnamed: 10k4.2, Q4.1
unnamed: 10k5.1, U3.9
unnamed: 10k5.2, Q5.1
unnamed: 10k6.1, U3.23
unnamed: 10k6.2, Q6.1
unnamed: 10k7.1, U3.19
unnamed: 10k7.2, Q7.1
unnamed: 10k8.1, U3.3
unnamed: 10k8.2, Q8.1
unnamed: 10k9.1, U3.2
unnamed: 10k9.2, Q9.1
unnamed: 10k10.1, U3.1
unnamed: 10k10.2, Q10.1
unnamed: 10k11.1, U3.32
unnamed: 10k11.2, Q11.1
unnamed: 10k12.1, U3.10
unnamed: 10k12.2, Q12.1
unnamed: 10k13.1, U3.11
unnamed: 10k13.2, Q13.1
unnamed: 10k14.1, U3.12
unnamed: 10k14.2, Q14.1
unnamed: 10k15.1, U3.13
unnamed: 10k15.2, Q15.1
unnamed: 10k16.1, U3.14
unnamed: 10k16.2, Q16.1
unnamed: D1.1, D2.1, D3.1, D4.1, D5.1, D6.1, D7.1, D8.1, Q6.3
unnamed: D1.2, D9.2, D17.2, D25.2, D33.2, D41.2, D49.2, D57.2, R9.1
unnamed: D9.1, D10.1, D11.1, D12.1, D13.1, D14.1, D15.1, D16.1, Q8.3
unnamed: D2.2, D10.2, D18.2, D26.2, D34.2, D42.2, D50.2, D58.2, R8.1
unnamed: D3.2, D11.2, D19.2, D27.2, D35.2, D43.2, D51.2, D59.2, R7.1
unnamed: D4.2, D12.2, D20.2, D28.2, D36.2, D44.2, D52.2, D60.2, R6.1
unnamed: D5.2, D13.2, D21.2, D29.2, D37.2, D45.2, D53.2, D61.2, R5.1
unnamed: D6.2, D14.2, D22.2, D30.2, D38.2, D46.2, D54.2, D62.2, R4.1
unnamed: D7.2, D15.2, D23.2, D31.2, D39.2, D47.2, D55.2, D63.2, R3.1
unnamed: D8.2, D16.2, D24.2, D32.2, D40.2, D48.2, D56.2, D64.2, R2.1
unnamed: D17.1, D18.1, D19.1, D20.1, D21.1, D22.1, D23.1, D24.1, Q7.3
unnamed: D25.1, D26.1, D27.1, D28.1, D29.1, D30.1, D31.1, D32.1, Q5.3
unnamed: D33.1, D34.1, D35.1, D36.1, D37.1, D38.1, D39.1, D40.1, Q4.3
unnamed: D41.1, D42.1, D43.1, D44.1, D45.1, D46.1, D47.1, D48.1, Q3.3
unnamed: D49.1, D50.1, D51.1, D52.1, D53.1, D54.1, D55.1, D56.1, Q2.3
unnamed: D57.1, D58.1, D59.1, D60.1, D61.1, D62.1, D63.1, D64.1, Q1.3
unnamed: J1.3, U3.24
unnamed: J2.1, U3.17
unnamed: J2.2, U3.16
unnamed: J2.3, U3.15
unnamed: J3.1, R1.2, U3.29
unnamed: J3.2, U3.30
unnamed: J3.3, U3.31
unnamed: Q9.2, R9.2
unnamed: Q10.2, R8.2
unnamed: Q11.2, R7.2
unnamed: Q12.2, R6.2
unnamed: Q13.2, R5.2
unnamed: Q14.2, R4.2
unnamed: Q15.2, R3.2
unnamed: Q16.2, R2.2
unnamed: R5000.2, U3.20
unnamed: U3.7, Y1.3
unnamed: U3.8, Y1.1

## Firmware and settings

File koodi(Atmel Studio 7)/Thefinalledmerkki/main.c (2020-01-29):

#include <avr/io.h>
#include <avr/pgmspace.h>
#include <string.h>
#include <stdio.h>
#include <avr/interrupt.h>
#include <util/delay.h>

#define FFT_N 128  //128, 256 work (but not 64)

#include "ffft.h"


void printLed(int row, int column);
void printColumn(int level);
void handleNewData(uint16_t spectrum[]);
void closeLed();
void ledTest();


// FFT defines and globals
#define ADC_CHANNEL 1
int16_t       capture[FFT_N];    // Audio capture buffer
complex_t     bfly_buff[FFT_N];  // FFT "butterfly" buffer
uint16_t      spectrum[FFT_N/2]; // Spectrum output buffer
volatile uint8_t samplePos = 0;     // Buffer position counter
uint16_t resultSpectrum[8] = {0,0,0,0,0,0,0,0};
uint16_t newData[8] = {0,0,0,0,0,0,0,0};



// Set the ADC up to run in free-running mode
void fftlib_init_adc(void) {
	// Init ADC free-run mode; f = ( 16MHz/prescaler ) / 13 cycles/conversion
	ADMUX  = ADC_CHANNEL; // Channel sel, right-adj, use AREF pin
	ADCSRA = _BV(ADEN)  | // ADC enable
	_BV(ADSC)  | // ADC start
	_BV(ADATE) | // Auto trigger
	_BV(ADIE)  | // Interrupt enable
	_BV(ADPS2) | _BV(ADPS1) | _BV(ADPS0); // 128:1 / 13 = 9615 Hz
	ADCSRB = 0;                // Free ru mode, no high MUX bit
	DIDR0  = 1 << ADC_CHANNEL; // Turn off digital input for ADC pin
	TIMSK0 = 0;                // Timer0 off --> this will stop the delay() function from working properly, but doesn't seem to affect the FFT

	sei(); // Enable interrupts
	
	memset(spectrum, 0, sizeof(spectrum));
}

// Audio-sampling interrupt
ISR(ADC_vect) {
	static const int16_t noiseThreshold = 4;
	int16_t sample = ADC; // 0-1023

	capture[samplePos] =
	((sample > (512 - noiseThreshold)) &&
	(sample < (512 + noiseThreshold))) ? 0 :
	sample - 512; // Sign-convert for FFT; -512 to +511

	if(++samplePos >= FFT_N) ADCSRA &= ~_BV(ADIE); // Buffer full, interrupt off
}

int main(void)
{	
	
	// Start the ADC in free running mode
	fftlib_init_adc();
	
	while (1)
	{
		// Compute the FFT
		fft_input(capture, bfly_buff);   // Samples -> complex #s
		samplePos = 0;                   // Reset sample counter
		ADCSRA |= _BV(ADIE);             // Resume sampling interrupt
		fft_execute(bfly_buff);          // Process complex data
		fft_output(bfly_buff, spectrum); // Complex -> spectrum
		
		
		// Print the results+
		handleNewData(spectrum);		//convert the new data to fit 8x8 matrix
		
		for(int j = 0; j < 8; j++){		//drop the level by one if no bigger peak is present in the new data
			if(newData[j] >= resultSpectrum[j]){
				resultSpectrum[j] = newData[j];	
			}
			else if(resultSpectrum[j] != 0){
				resultSpectrum[j] -= 1;
			}

		}
		
		for (int j = 0; j < 2; j++){	//print twice in order to increase brightness
			for (int i = 0; i < 8; i++){
//				ledTest();				//uncomment to enable led test pattern
				printLed(i, resultSpectrum[i]);
			}
		}
	}
}

void printLed(int row, int column){		//handle printing on leds
	if(row == 0){						//decide which row has to be activated
		PORTC |= 0b00010000;
	}
	else if(row == 1){
		PORTC |= 0b00001000;
	}
	else if(row == 2){
		PORTC |= 0b00000100;
	}
	else if(row == 3){
		PORTC |= 0b00100000;
	}
	else if(row == 4){
		PORTD |= 0b00100000;
	}
	else if(row == 5){
		PORTE |= 0b00000100;
	}
	else if(row == 6){
		PORTE |= 0b00000001;
	}
	else if(row == 7){
		PORTC |= 0b00000001;
	}
	printColumn(column);
	_delay_ms(1);
	closeLed();
}


void closeLed(){						//close the ports to avoid multiple rows to be on at the same time
	PORTC &= 0b11000010;
	PORTD &= 0b00000011;
	PORTE &= 0b11111010;
	PORTB &= 0b11111000;
}

void ledTest(){
while(1){
	printLed(0,8);
	_delay_ms(1000);
	printLed(1,8);
	_delay_ms(1000);
	printLed(2,8);
	_delay_ms(1000);
	printLed(3,8);
	_delay_ms(1000);
	printLed(4,8);
	_delay_ms(1000);
	printLed(5,8);
	_delay_ms(1000);
	printLed(6,8);
	_delay_ms(1000);
	printLed(7,8);
	_delay_ms(1000);
}
}

void printColumn(int level){			//open column ports the right amount
	if(level > 0){
		PORTB |= 0b00000100;
		if(level > 1){
			PORTB |= 0b00000010;
				if(level > 2){
					PORTB |= 0b00000001;
						if(level > 3){
							PORTD |= 0b10000000;
								if(level > 4){
									PORTD |= 0b01000000;
										if(level > 5){
											PORTD |= 0b00000100;
												if(level > 6){
													PORTD |= 0b00001000;
														if(level > 7){
															PORTD |= 0b00010000;
														}
												}
										}
								}
						}
				}
		}
	}
}





void handleNewData(uint16_t spectrum[]){
	uint16_t noise[8]={12,4,2,3,1,1,1,2};			//noise level, can be edited to fit better
	int result = 0;
	int helper = 0;
	for(int i = 0; i < 64; i++){
		result += spectrum[i];
		if(((i+1) % 8 == 0) && ((i+1) != 0)){
				helper = (i+1)/8 - 1;
				result /= 8;
					
				newData[helper] = result;
				result = 0;
					
				if(newData[helper] < noise[helper]){
					newData[helper] = 0;
				}
				else{
					newData[helper] = newData[helper] - noise[helper];
				}
				if(newData[helper] > 8){
					newData[helper] = 8;
				}
		}
	}
}
